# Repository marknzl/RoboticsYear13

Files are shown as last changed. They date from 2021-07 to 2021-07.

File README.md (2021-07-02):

# RoboticsYear13
Repo containing my robotics work from year 13  
__NOTE: This is all my original work from year 13; no modifications have been made whatsoever since 2019.__

# Project Objective
The objective of this project was to construct an autonomous line-following "warehouse" robot that can navigate using sensors, pick up a payload, and drop it off at an endpoint. I ended up implementing manual control via bluetooth for fun which allows the user to switch from autopilot to manual control seamlessly :) 

# Project Structure

## Robot Software
All my robot code is stored here. I used the Arduino IDE to write the robot software (hence the `.ino` extension), and each file in the folder handles a certain aspect of the robot's functionality.

## Control Software
This folder consists of one project (RobotController) which is a tiny piece of software I wrote to manually control my robot's operations. It's written in C# and uses the WPF framework for UI stuff. The program interfaces with the robot via bluetooth by allowing the user to select a virtual serial port assigned to the bluetooth device; hence achieving a level of abstraction which allows me to disregard the actual connection medium (e.g USB, bluetooth...)

## Utility Software
There are two main C# projects under the `Utility Software` folder - namely `AverageLatency` and `SensorUtility`. I also wrote a small helper library `SerialProvider` for serial port access which is used across the two other projects.

### Average Latency
This is a lightweight program that I wrote to, well, test out the average bluetooth latency between my robot and my laptop for testing purposes.

### SensorUtility
The `SensorUtility` program is a small program to take in sensor readings from the four sensors on my robot and format the data nicely in an `.csv` file along with other statistics such as averages and standard deviation.

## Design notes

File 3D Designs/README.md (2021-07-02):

# 3D Designs

## Intro
All parts for my robot (apart from the electrical components) were custom designed and 3D modelled using SOLIDWORKS and then 3D printed. This process was highly iterative and as a result it took quite a few attempts to get my desired end result. All 3D models are provided under `/models` and can be opened using SOLIDWORKS or Autodesk Inventor.

## Screenshots
Due to the amount of parts, I can't include screenshot of all parts but here are a select few:

### Robot assembly (`Full assembly.SLDASM`)
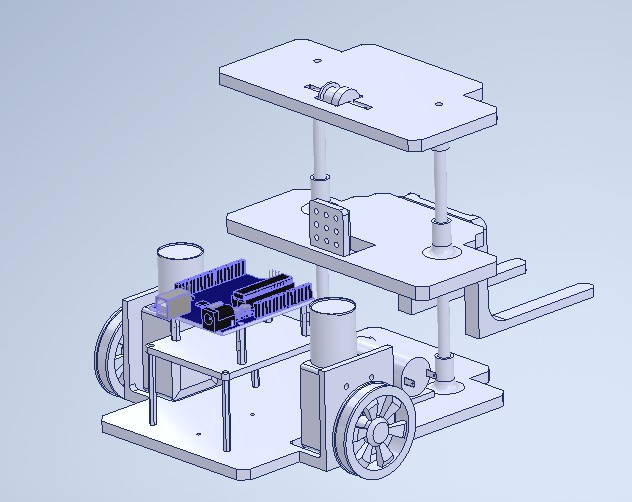
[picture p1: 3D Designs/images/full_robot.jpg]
Full Robot Full robot assembly
  
_The space at the bottom of the Arduino mount is for the battery pack :)_

### Limit Switch Trigger (`Limit switch trigger (for top).SLDPRT`)

#### Model
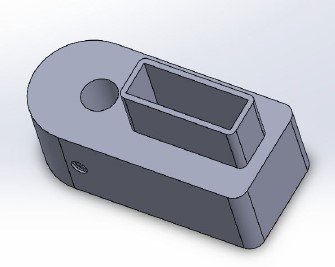
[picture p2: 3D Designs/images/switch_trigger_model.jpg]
switch_trigger_model


### Final product
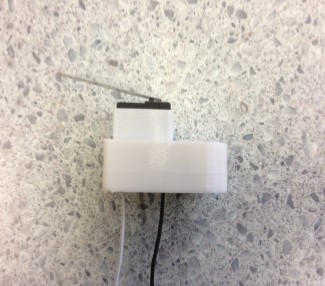
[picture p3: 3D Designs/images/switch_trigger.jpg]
Switch Trigger


### Wheel (`Wheel (New).SLDPRT`)
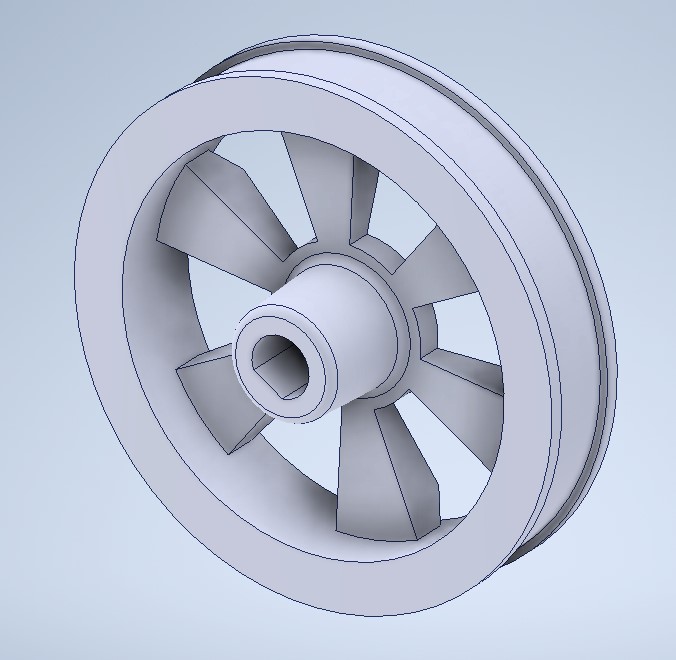
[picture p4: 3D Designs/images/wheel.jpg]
Wheel


### Forklift (`Forklift - Front (v2).SLDPRT`)
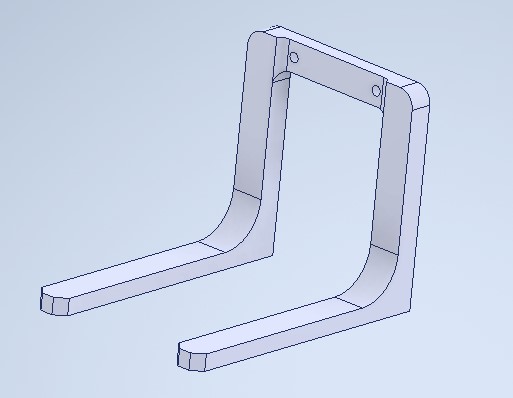
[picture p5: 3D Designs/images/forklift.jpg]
Forklift


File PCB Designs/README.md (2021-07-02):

# PCB Designs

## Intro
For my robot, I had designed and produced two PCBs - a main PCB shield that plugs into an Arduino Uno, and a tiny sensor board that just contains an LDR and an LED. The PCBs were fabricated using a monoFab SRM-20 desktop CNC mill.

## Main PCB
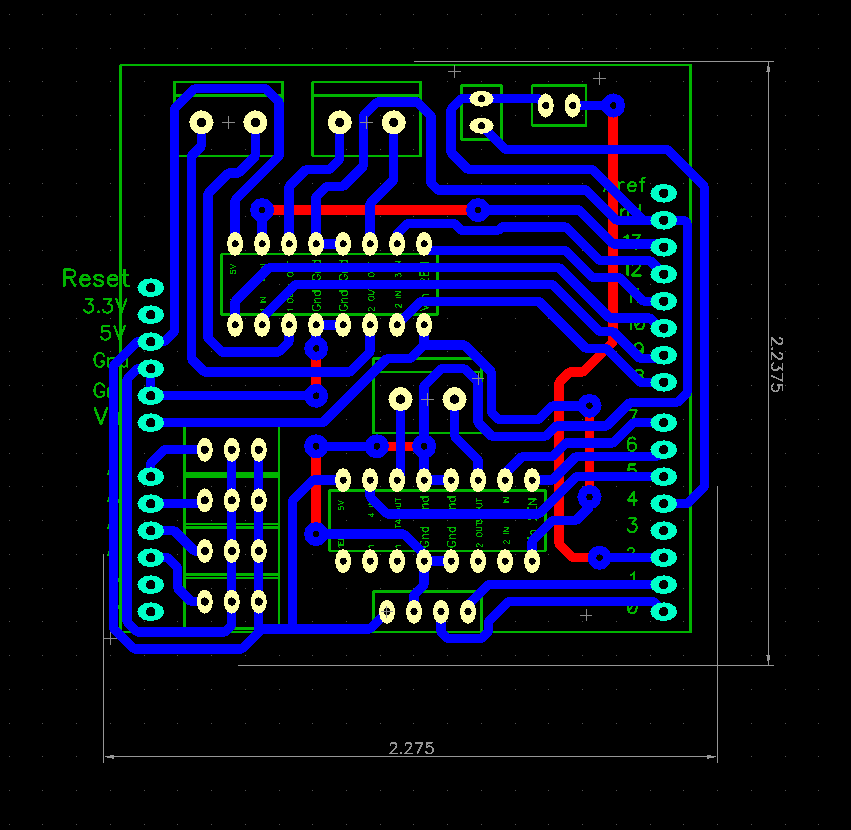
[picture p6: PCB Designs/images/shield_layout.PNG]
Shield Layout


This is the main circuit for my robot which is a shield that just plugs into an Arudino Uno.  

The two chips are `L293D` motor drivers used to power the two main motors of the robot + the pulley motor for the forklift. In the bottom-left, the four 3-pin headers are for my light sensors, and these connect to the Arduino's analog-in ports. The four-pin header at the bottom is for the bluetooth module which is connected to pins `0` and `1` for `RX/TX`. In the top-right, the two small two-pin headers are for the limit switches which allow me to determine programatically when the forklift has reached the top/bottom. Finally, the two larger two-pin headers in the top-left are for the main motors and middle one is for the pulley motor.

## Sensor PCB
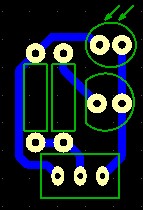
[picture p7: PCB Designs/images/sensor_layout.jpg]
Sensor Layout


This is the sensor circuit for my robot which plugs into my main PCB shield.

This circuit simply contains an LED, LDR, and a 3-pin header which allows me to connect the sensor PCB to the main PCB shield.

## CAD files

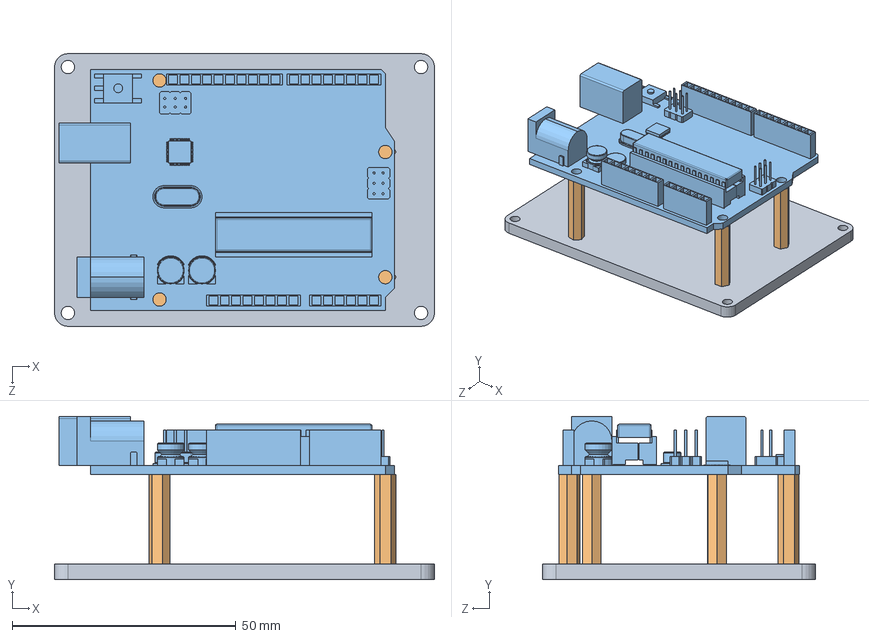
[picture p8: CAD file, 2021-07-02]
3D Designs/models/Arduino test.SLDASM
85.0 x 36.5 x 61.0 mm
Arduino mount - Newest (no mount)
Standoff - small x 4
Arduino Uno R3

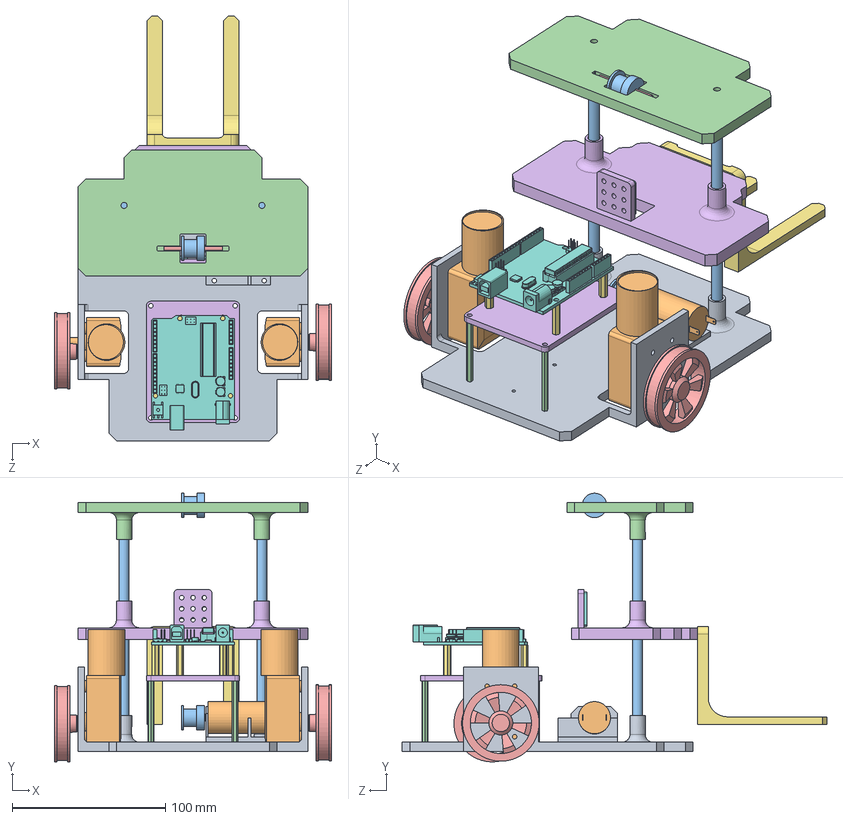
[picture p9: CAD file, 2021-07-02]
3D Designs/models/Full assembly (Test).SLDASM
181.0 x 175.5 x 277.5 mm
Base
Motor x 2
Pole x 2
Standoff x 4
Wheel (New) x 2
Arduino mount - Newest (no mount)
Standoff - small x 4
Arduino Uno R3
Pulley mount (new)
Pulley motor
Pulley (new) x 2
Forklift - Top (New v2)
Axle
Forklift - Moving (New v5)
Forklift - Front (v2)
Timing belt fastener

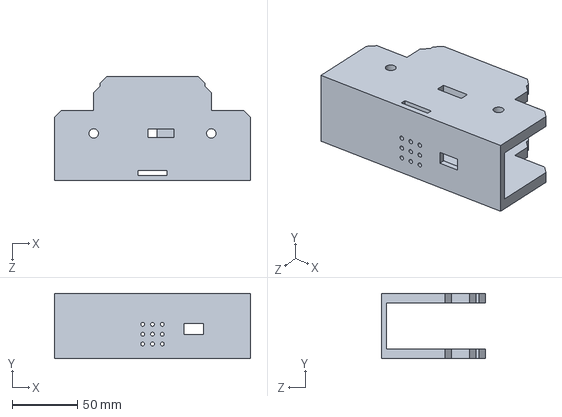
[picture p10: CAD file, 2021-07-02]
3D Designs/models/Forklift - Moving (New).SLDPRT
150.0 x 50.0 x 79.8 mm

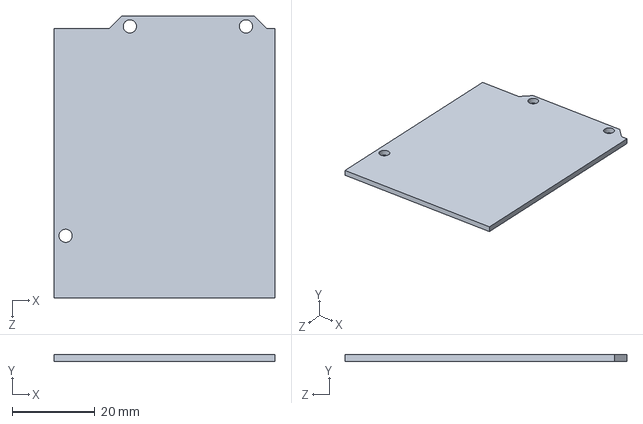
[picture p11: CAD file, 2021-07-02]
3D Designs/models/Arduino model - custom.SLDPRT
53.3 x 1.60 x 68.0 mm

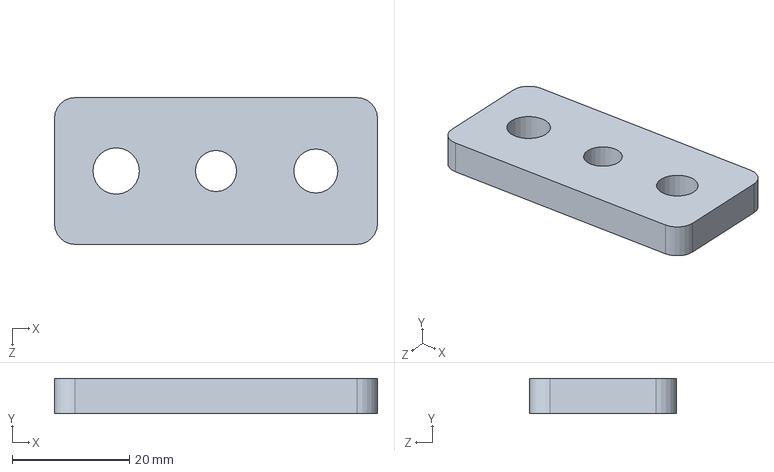
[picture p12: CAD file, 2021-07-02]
3D Designs/models/Pole tester.SLDPRT
55.0 x 6.00 x 25.0 mm

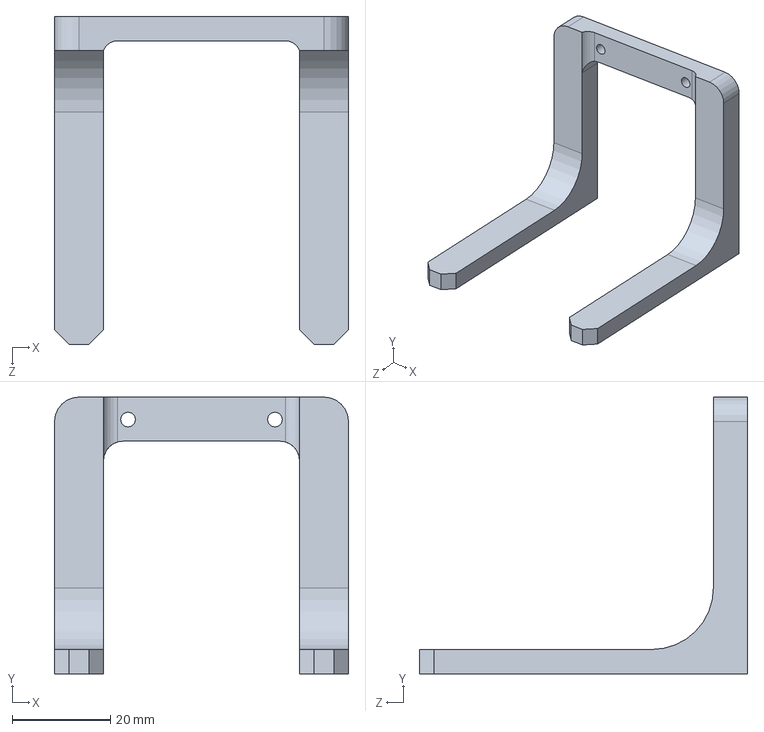
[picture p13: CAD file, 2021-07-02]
3D Designs/models/Forklift - Front.SLDPRT
60.0 x 56.5 x 67.0 mm

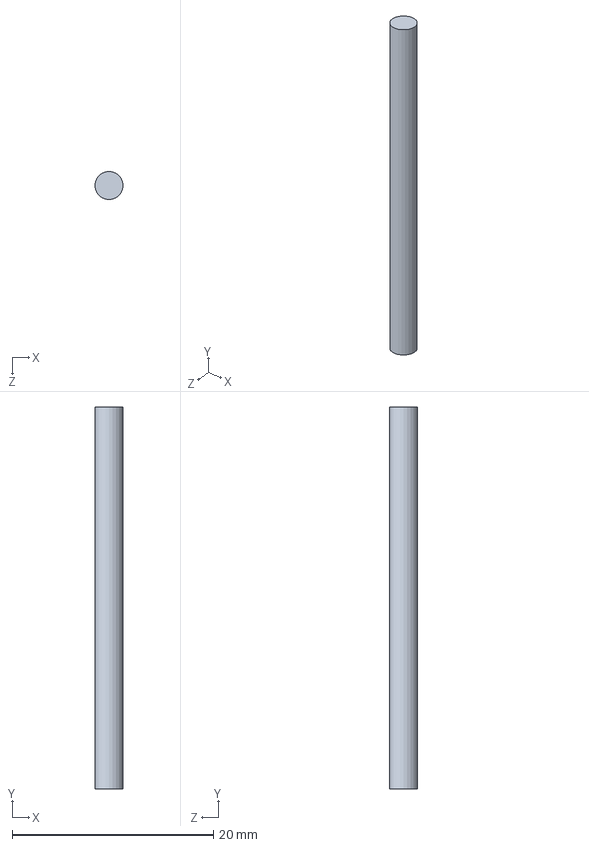
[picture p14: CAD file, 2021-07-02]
3D Designs/models/Axle.SLDPRT
2.80 x 38.0 x 2.80 mm

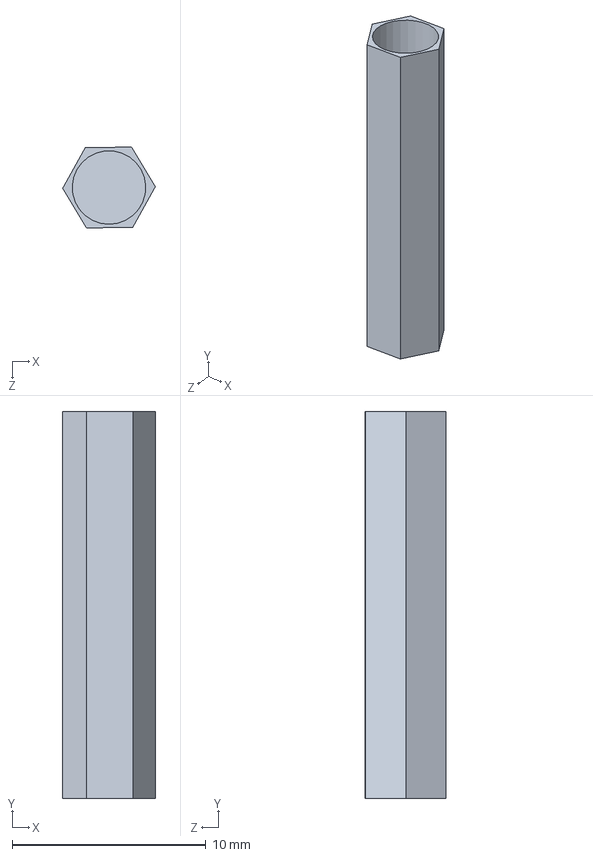
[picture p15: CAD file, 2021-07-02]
3D Designs/models/Standoff - small.SLDPRT
4.79 x 20.0 x 4.19 mm

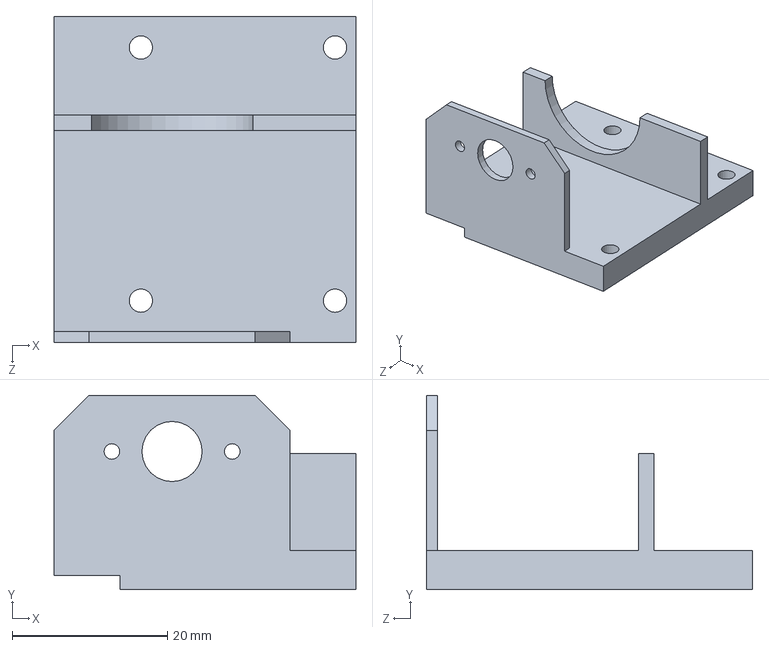
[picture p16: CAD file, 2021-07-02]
3D Designs/models/Pulley mount (new).SLDPRT
38.9 x 25.0 x 42.0 mm

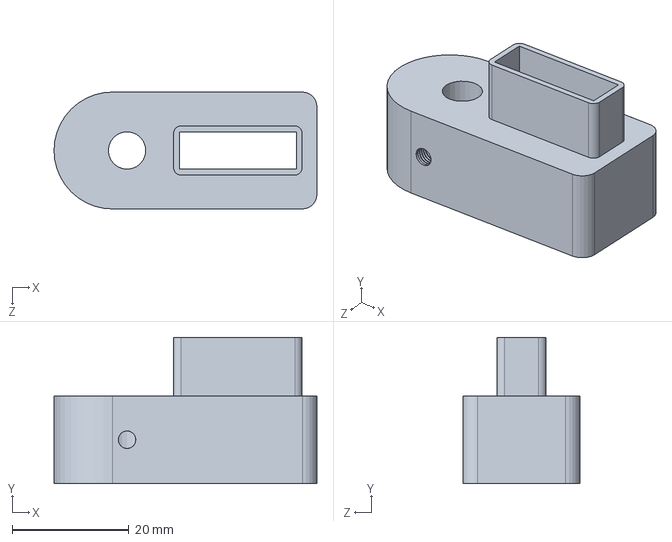
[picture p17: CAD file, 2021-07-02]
3D Designs/models/Limit switch trigger (for top).SLDPRT
45.0 x 25.0 x 20.0 mm

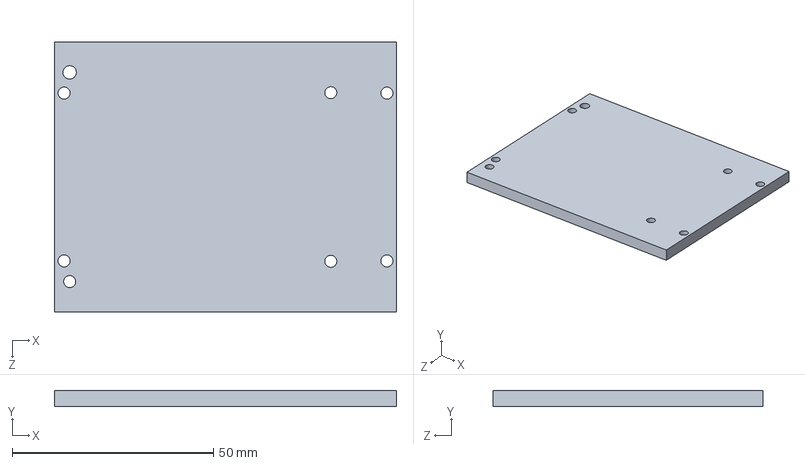
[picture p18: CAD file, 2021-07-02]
3D Designs/models/Arduino mount.SLDPRT
85.0 x 4.00 x 67.0 mm

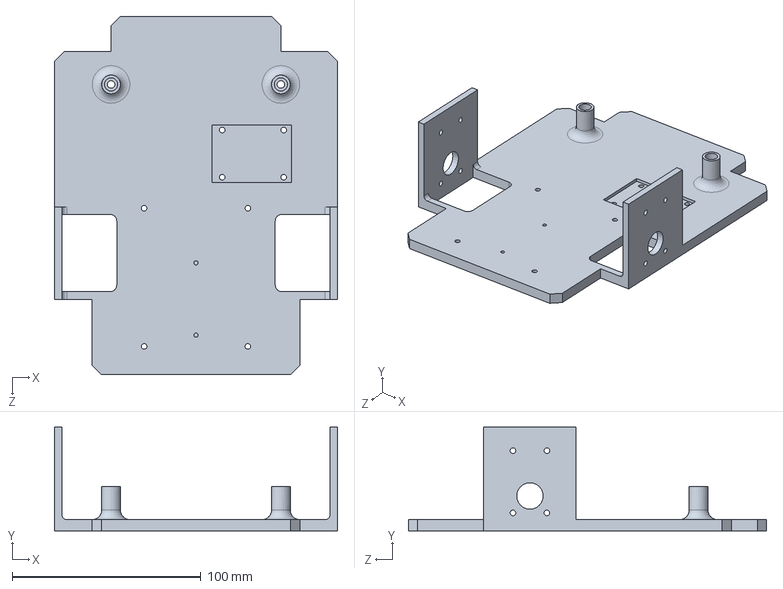
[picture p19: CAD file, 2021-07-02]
3D Designs/models/Base.SLDPRT
150.0 x 55.0 x 190.0 mm

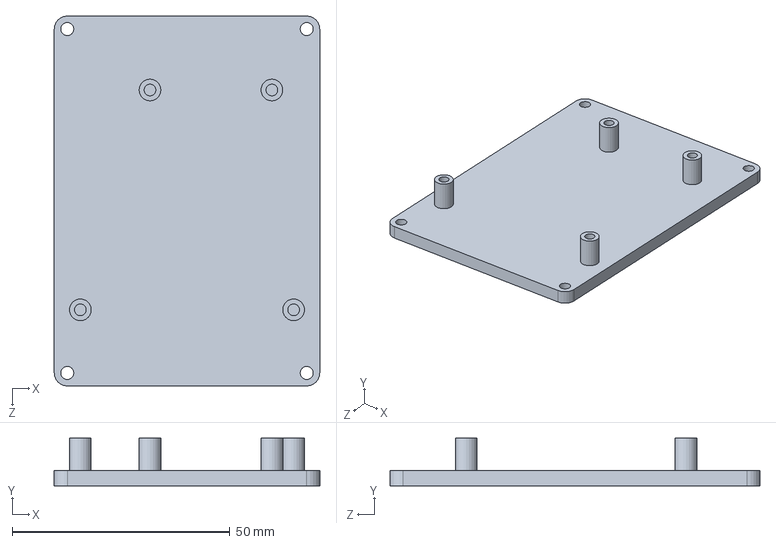
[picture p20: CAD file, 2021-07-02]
3D Designs/models/Arduino mount - Newest.SLDPRT
61.0 x 11.0 x 85.0 mm

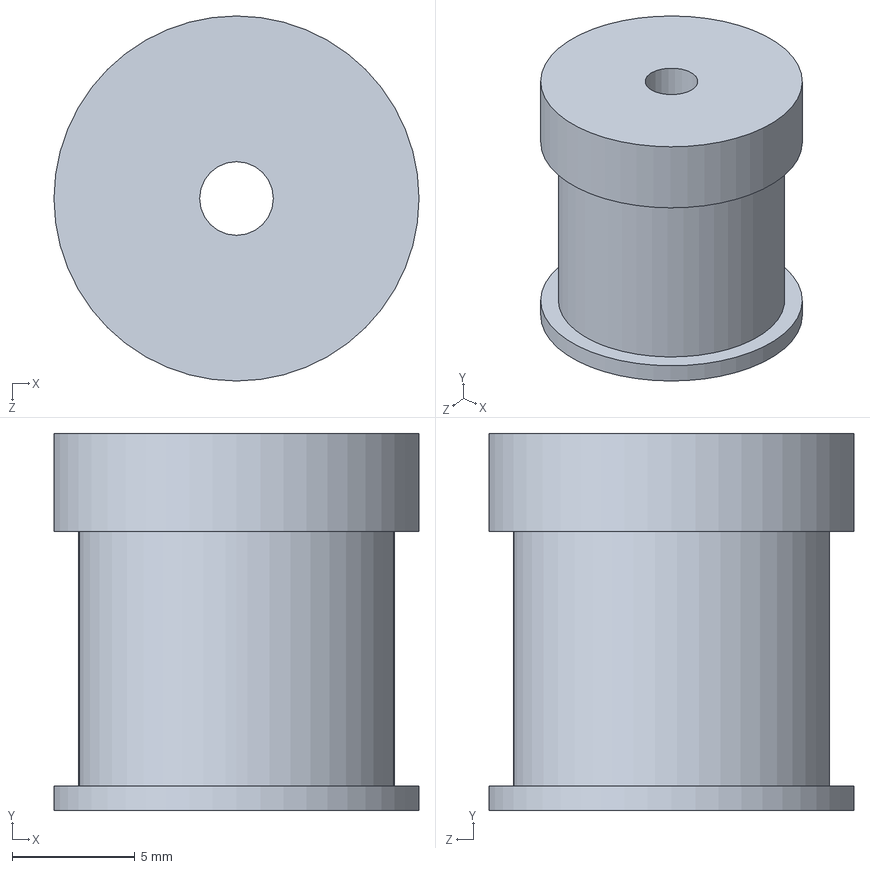
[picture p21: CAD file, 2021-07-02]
3D Designs/models/Pulley.SLDPRT
14.9 x 15.4 x 14.9 mm

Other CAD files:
3D Designs/models/Pallet.SLDPRT
3D Designs/models/Pulley mount.SLDPRT
3D Designs/models/Motor.SLDPRT
3D Designs/models/Arduino Uno R3.SLDPRT
3D Designs/models/Arduino holder - custom.SLDPRT
3D Designs/models/Arduino mount - New.SLDPRT
3D Designs/models/Arduino mount - Newest (no mount).SLDPRT
3D Designs/models/Batter pack.SLDPRT
3D Designs/models/Cylinder.SLDPRT
3D Designs/models/Forklift - Front (v2).SLDPRT
3D Designs/models/Forklift - Moving (New v2).SLDPRT
3D Designs/models/Forklift - Moving (New v3).SLDPRT
3D Designs/models/Forklift - Moving (New v4).SLDPRT
3D Designs/models/Forklift - Moving (New v5).SLDPRT
3D Designs/models/Forklift - Moving.SLDPRT
3D Designs/models/Forklift - Top (New ).SLDPRT
3D Designs/models/Forklift - Top (New v2).SLDPRT
3D Designs/models/Forklift - Top.SLDPRT
3D Designs/models/Limit switch trigger.SLDPRT
3D Designs/models/Limit switch.SLDPRT
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

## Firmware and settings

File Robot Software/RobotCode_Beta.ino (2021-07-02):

#include <ArduinoJson.h>

///MOTORS////////////////
// LEFT MOTOR: 8, 9
// RIGHT MOTOR: 12, 13
// PULLEY: 7, 5
/////////////////////////
///SENSORS///////////////
// LEFT TOP: A5
// LEFT BOTTOM: A4
// RIGHT TOP: A2
// RIGHT BOTTOM: A3
/////////////////////////
///LIMIT SWITCH//////////
// PIN: 2
// PIN: 4
/////////////////////////

// Sensor analog pins
const int TOP_LEFT_SENSOR = A2; // Top left
const int BOTTOM_LEFT_SENSOR = A3; // Bottom left
const int TOP_RIGHT_SENSOR = A0; // Top right
const int BOTTOM_RIGHT_SENSOR = A1; // Bottom right

// Calibration thresholds
double topLeftThreshold = 0;
double topRightThreshold = 0;
double bottomLeftThreshold = 0;
double bottomRightThreshold = 0;

// Limit switch pins
const int TOP_LIMIT_SWITCH = 4;
const int BOTTOM_LIMIT_SWITCH = 2;

// State variables
bool manualControl = false;
bool startedReadings = false;
bool reachedEndpoint = false;
bool hasTurned = false;
bool returning = false;

void setup()
{
  Serial.begin(9600);

  pinMode(8, OUTPUT);
  pinMode(9, OUTPUT);
  pinMode(12, OUTPUT);
  pinMode(13, OUTPUT);
  pinMode(7, OUTPUT);
  pinMode(5, OUTPUT);
  pinMode(TOP_LIMIT_SWITCH, INPUT_PULLUP);
  pinMode(BOTTOM_LIMIT_SWITCH, INPUT_PULLUP);
  //getSensorData(100);
  //calibrateForklift();
  //reachSurfaceLevel();
  //lineFollowingCalibration();
  //cornerDetectionCalibration();
  calibrateSensors();
}

void loop()
{
  while (manualControl)
  {
    while (Serial.available())
    {
      char c = Serial.read();
      parseMessage(c);
    }
  }

  // If manual control is toggled off, the autopilot will take over robot control
  char c = Serial.read();
  if (c == 'Q')
  {
    manualControl = true;
    freeze();
    Serial.println("Autopilot disabled! Turning on manual control");
  }

  followLine();

  if (!hasTurned)
    checkForCorner();

  if (!returning)
  {
    checkForEndpoint();
  } else
  {
    checkForOrigin();
  }

  //sensorReadings();
}

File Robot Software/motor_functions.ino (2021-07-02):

// Makes the robot go forwards
void forward() 
{
  digitalWrite(8, LOW);
  digitalWrite(9, HIGH);
  digitalWrite(10, 150);
  
  digitalWrite(12, LOW);
  digitalWrite(13, HIGH);
  digitalWrite(11, 150);
}

// Makes the robot go backwards
void backward() 
{
  digitalWrite(8, HIGH);
  digitalWrite(9, LOW);
  analogWrite(10, 220);
  
  digitalWrite(12, HIGH);
  digitalWrite(13, LOW);
  analogWrite(11, 220);
}

// Makes the robot turn left
void turnLeft() 
{
  digitalWrite(8, LOW);
  digitalWrite(9, HIGH);
  analogWrite(10, 220);
  
  digitalWrite(12, HIGH);
  digitalWrite(13, LOW);
  analogWrite(11, 150);
}

void turnLeftBackward()
{
  digitalWrite(8, LOW);
  digitalWrite(9, HIGH);
  
  digitalWrite(12, HIGH);
  digitalWrite(13, LOW);
}

void turnRightBackward()
{
  digitalWrite(8, HIGH);
  digitalWrite(9, LOW);
  
  digitalWrite(12, LOW);
  digitalWrite(13, HIGH);
}

// Makes the robot turn right
void turnRight() 
{
  digitalWrite(8, HIGH);
  digitalWrite(9, LOW);
  analogWrite(10, 255);
  
  digitalWrite(12, LOW);
  digitalWrite(13, HIGH);
  analogWrite(11, 255);
}

// Makes the robot come to a standstill
void freeze()
{
  digitalWrite(8, LOW);
  digitalWrite(9, LOW);
  digitalWrite(12, LOW);
  digitalWrite(13, LOW);
}
